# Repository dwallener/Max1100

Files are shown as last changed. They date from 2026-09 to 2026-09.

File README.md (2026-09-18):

# Max 1100 cooling prototype

Current development: four GPUs at a hard **200 W per card**, horizontal motherboard, approximately 3 mm housing gaps. Build and test the suction duct before designing the enclosure.

- [Agreed plan](PROTOTYPE-PLAN.md)
- [Fabrication notes and physical test sequence](FABRICATION-200W.md)
- [200 W prototype CAD source](prototype-200w.scad)
- [Individual STL and gasket DXF parts](prototype-200w/parts/)
- [Exploded assembly](prototype-200w/assembly.png)
- [Blower support layout](prototype-200w/support-layout.svg)
- [200 W versus preserved 300 W design](COMPARISON.md)

## Print first: the fit coupon

Print [fit-coupon.stl](prototype-200w/parts/fit-coupon.stl) on its broad face: approximately 78 × 117 mm on the bed and 6 mm tall. PLA is suitable for this unpowered fit check. Try it over two adjacent GPU housing ends without forcing it or pressing against circuit boards or fins. This checks the approximate housing profile and 3 mm gap before committing to larger prints.

After the coupon fits, trial the complete four-card adapter and connected cable/bracket clearance. The remaining duct parts are approximate development geometry, not thermally validated hardware. No native Onshape document has been created; source CAD is OpenSCAD.

## Rebuilding the exports

Install OpenSCAD and make its `openscad` command available on your PATH, then run from the repository root:

```sh
sh prototype-200w/export.sh
```

The script regenerates the individual STL parts, gasket DXFs and exploded assembly PNG. CAD sources, fabrication exports, previews and manufacturer reference files are tracked so the project can be reviewed and the fit coupon printed without installing CAD software. Export logs, local editor files and duplicate build-package ZIPs are ignored. `part-sizes.json` records the current exported mesh bounds; the export script does not regenerate that report.

The earlier `duct-v1.*`, `DESIGN.md` and `BLOWER-SELECTION.md` describe the preserved 300 W alternative. `duct-200w.*` retain the earlier complete 200 W concept including the blower envelope. `prototype-200w.scad` adds fabrication details without overwriting either concept.

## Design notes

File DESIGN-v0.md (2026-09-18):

# Max 1100 duct prototype, revision 0

Status: packaging concept; not a fabrication release or thermally validated design. No Onshape document has been created. Editable geometry is in duct-v0.scad. All dimensions are millimetres.

## Architecture

Four cards in parallel, each drawing room air through its own heatsink. A sealed card-end adapter feeds a shared suction chamber, a gradual rectangular-to-round transition, and a short 200 mm duct to a separate housed, speed-controlled centrifugal blower. Exhaust stays away from GPU intakes. No 40 mm fans. Motherboard remains horizontal, cards vertical in slots as photographed. CPU cooling is separate and is outside this prototype.

The collector is independently supported. Soft seals contact the card housings, never bare boards or heatsink fins. Bridge, PCIe slots and power connectors carry no duct load. The photographed connector/extension-bracket end is a provisional collector location, NOT a confirmed Intel airflow direction. Verify direction from integration guidance or controlled comparison before fitting the end adapter.

## Airflow basis

Intel datasheet revision 1.0, page 32 gives card pressure drop:

    pressure_inH2O = -0.0137 + 0.0127*q + 0.0007*q^2 - 0.0000002*q^3
    q = per-card flow in CFM; 1 inH2O = 249.09 Pa

At 30 CFM/card: 0.9919 inH2O = 247 Pa; total four-card flow is 120 CFM.
At 40 CFM/card: 1.6015 inH2O = 399 Pa; total four-card flow is 160 CFM.
Parallel cards add flow, not pressure. Assumes comparable paths and good seals.

Initial blower procurement envelope: a manufacturer-confirmed operating point of at least 160 CFM (272 m3/h) at 500 Pa external static pressure, with speed control. This provides a provisional ~100 Pa allowance above the 40 CFM/card curve point for the duct, seals and guards. It is NOT measured system resistance, a guaranteed thermal requirement, or permission to substitute a 160 CFM free-air rating and a separate 500 Pa shutoff rating. Check hot-air rating and the actual housed blower curve. No particular blower is selected yet.

At 120 / 160 CFM total, 1,200 W gives ideal bulk air rises of approximately 17.6 / 13.2 C, using air density 1.2 kg/m3 and cp 1005 J/kg K. These do not predict GPU/HBM temperatures. Intel page 29 separately specifies approach velocity versus inlet temperature; establish the relevant inlet measurement area and check that requirement during testing. Do not convert using an assumed open-fin area.

Intel source: https://cdrdv2-public.intel.com/817799/817799_Intel%20Data%20Center%20GPU%20Max%201100%20Datasheet_Rev_1_0.pdf

## Geometry and fabrication status

- Card reference envelopes: 266.7 long, 111.15 high, 34.35 wide (Intel table); assumed 40.64 pitch. Actual seal profile is smaller/different from the full card envelope and must be measured.
- Collector clear section: 180 x 130, length 120. Deliberate service room for cable routing and projecting brackets; check actual harness bend requirements.
- Transition: 220 long, from collector section to 200 clear-diameter outlet. Outlet collar: 40 long. Wall: 3. Joining flanges: 5 thick, 14 wide, M4 clearance holes.
- Approximate duct body length: 380, excluding blower/connecting hose. Envelope including front flanges: 214 wide by 220 high. These are adjustable design choices.
- SCAD includes collector, transition, outlet and reference card boxes. It does NOT include the fitted card-end seal plate, between-card bypass seals, cable pass-throughs, service lid, brackets, pressure taps, guards, print splits or blower mounting. These must be detailed before fabrication.
- Use a sheet-metal collector with removable gasketed lid for first thermal testing; printed transition/collar are options after material temperature limits are checked. Do not assume a printed polymer is suitable from room-temperature fit alone.
- Transition and collar meet at a butt seam in the concept. Add a bonded sleeve or bolted joint before separate fabrication. The 220 mm transition may need splitting for the available printer.

## Test that decides whether to build the enclosure

1. Fit seals and supports with power off. Install a proper CPU/cooler and support the motherboard on standoffs for powered tests. Route and secure GPU power cables, maintaining manufacturer bend clearance. Install blower guard and proper power/control hardware.
2. Run blower first, check bypass leakage and inlet/exhaust separation. Use pressure taps in calm regions upstream and downstream of the card bank with a differential manometer. Keep taps clear of jets. A bank pressure reading cannot prove equal flow through each card.
3. At conservative GPU power, record room/card inlet temperatures, GPU/HBM temperatures, each card's power, clocks and thermal-throttle flags, blower speed, differential pressure and sound at a fixed distance. Log every card, not just an average.
4. Increase load/power in steps, then operate all four at the intended 300 W/card and representative workload. Observe until temperatures settle, then sustain at least 30 minutes. Stop escalation on throttle, uncontrolled temperature rise or any component limit. Test inlet temperature expected in actual use.
5. Pass only with no thermal throttling, sustained intended performance, temperatures below published limits with useful margin, and acceptable measured noise. Use 90 C GPU/HBM as an initial conservative project target, not an Intel specification; verify valid HBM sensor channels and all component-specific limits. Intel notes a disabled HBM stack can report invalid values.
6. Reduce blower speed to find the quietest passing operating point. If one card is hotter, inspect its inlet, seals and obstruction before adding speed. Repeat at maximum expected room temperature and after adding the enclosure/filter/guards because those change resistance.
7. Before unattended operation, tie loss of blower/airflow to workload stop or shutdown. Never rely on a static CAD model to establish thermal safety.

Next physical inputs: actual four-card end profile/pitch, bracket and connected-cable envelope, and intended airflow direction. These are fit-release requirements, not prerequisites to discussing this concept.

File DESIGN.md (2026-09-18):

# Max 1100 cooling prototype, revision 1

Selected blower: Fantech FG 12XL EC #49905, 120 V / 60 Hz. See [selection, evidence and bill of materials](BLOWER-SELECTION.md).

Current editable assembly: duct-v1.scad. duct-v1.stl contains only the custom duct. duct-v1.png shows the assembly. Revision 0 is retained separately for history.

## Current design

Four parallel GPU airflow paths feed a 180 x 130 mm clear collector, 120 mm long. A 550 mm transition leads to a 305 mm nominal connection and straight inlet spool. The purchased blower and its isolation connections sit on an independent frame. CPU and motherboard cooling remain separate. The full straight test layout is approximately 1,695 x 460 x 505 mm, including reference card envelopes.

Intel's pressure polynomial gives approximately 247 Pa at 30 CFM/card and 399 Pa at 40 CFM/card. Four parallel cards therefore need 120 or 160 CFM total at those pressures, plus duct losses. The initial allowance is 160 CFM at 500 Pa at reference density. Fantech's live calculator reaches that point at nearly full drive; hot-air reserve is limited. See the selection note for exact calculator results and limitations.

Status: model checked as manifold and rendered for visual inspection. It has not been fabricated, fit checked, structurally certified or thermally tested. The fan is a purchased-component clearance envelope, not a manufacturer CAD solid. There is no Onshape document yet.

Still required before fabrication: fitted card seals, cable exit profiles, actual GPU pitch, airflow-direction verification, service lid and print splits, collar attachment, and OEM blower bracket mounting holes. Verify purchased coupling fits and keep all assembly load off the GPUs. The blower can be moved remotely without changing the card collector.

## Test that decides whether to build the enclosure

1. Fit seals and supports with power off. Install a proper CPU/cooler and support the motherboard on standoffs for powered tests. Route and secure GPU power cables, maintaining manufacturer bend clearance. Install blower guard and proper power/control hardware.
2. Run blower first, check bypass leakage and inlet/exhaust separation. Use pressure taps in calm regions upstream and downstream of the card bank with a differential manometer. Keep taps clear of jets. A bank pressure reading cannot prove equal flow through each card.
3. At conservative GPU power, record room/card inlet temperatures, GPU/HBM temperatures, each card's power, clocks and thermal-throttle flags, blower speed, differential pressure and sound at a fixed distance. Log every card, not just an average.
4. Increase load/power in steps, then operate all four at the intended 300 W/card and representative workload. Observe until temperatures settle, then sustain at least 30 minutes. Stop escalation on throttle, uncontrolled temperature rise or any component limit. Test inlet temperature expected in actual use.
5. Pass only with no thermal throttling, sustained intended performance, temperatures below published limits with useful margin, and acceptable measured noise. Use 90 C GPU/HBM as an initial conservative project target, not an Intel specification; verify valid HBM sensor channels and all component-specific limits. Intel notes a disabled HBM stack can report invalid values.
6. Reduce blower speed to find the quietest passing operating point. If one card is hotter, inspect its inlet, seals and obstruction before adding speed. Repeat at maximum expected room temperature and after adding the enclosure/filter/guards because those change resistance.
7. Before unattended operation, tie loss of blower/airflow to workload stop or shutdown. Never rely on a static CAD model to establish thermal safety.

Next physical inputs: actual four-card end profile/pitch, bracket and connected-cable envelope, and intended airflow direction. These are fit-release requirements, not prerequisites to discussing this concept.

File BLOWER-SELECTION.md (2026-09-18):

# Selected blower and integration, revision 1

Selected for the prototype: **Fantech FG 12XL EC, item 49905, 120 V / single phase / 60 Hz**. This is a complete housed centrifugal inline fan. No purchase has been made. Current vendor stock, lead time and price have not been verified.

## Selection evidence

The live Fantech product selector and its embedded Systemair calculation tool were inspected on 2026-09-18. Product 49905, variant 99711, calculator version 2026-09-02.07:32. Source:
https://www.fantech.net/en-us/products/fans-and-accessories/inline-duct-fans/fg?sku=49905

At air density 0.075 lb/ft3, input 160 CFM and 2.01 in.wg (~501 Pa), the calculator returned:

| Quantity | Manufacturer calculator result |
|---|---:|
| Working airflow | 160 CFM |
| Working static pressure | 2.01 in.wg |
| Input power | 125 W |
| Fan speed | 2,635 RPM |
| Control signal | 9.8 V |
| Current | 1.60 A |
| Inlet sound power | 71 dB(A) |
| Outlet sound power | 73 dB(A) |

These are calculated fan operating-point data, not measurements of this GPU assembly. Sound power is NOT sound pressure at the listener and must not be advertised as a 73 dBA room noise level. The operating RPM differs from the nominal product-sheet RPM; it is reported as the calculator result without substituting it for the nameplate rating.

This meets our initial reference-density sizing point with little remaining speed-control margin. A second calculation at entered density 0.0675 lb/ft3 (display rounded to 0.068) returned 155 CFM, 2.09 in.wg and 10.0 V rather than the requested point. Thus it is NOT a verified 160 CFM / 500 Pa selection at hot exhaust density. System resistance also changes with density, but the actual nonuniform heated card/duct system must be measured. Do not assume constant cooling mass flow as air temperature rises. The selection is for the test prototype, not an unconditional thermal guarantee.

An older 2016 brochure lists a 1.96 in.wg shutoff pressure for the same model. The newer 2025 makeup-air table lists 2.51 in.wg. We used the live manufacturer's model-specific calculator instead of mixing those versions. Obtain a current submittal matching the supplied unit before purchasing old stock or a used blower.

The older FG8 EC and FG10 EC tables do not meet 160 CFM at 500 Pa; extra free-air capacity does not compensate for insufficient pressure. The selected 12-inch fan's size is accepted because the user prioritized function over footprint.

## Physical integration in duct-v1.scad

- Replace the earlier 200 mm outlet with **305 mm nominal duct size**. Printed adapter is 305 mm OD / 299 mm ID, 3 mm wall. This is an interface design choice; measure fan spigot OD and chosen clamp fit before printing. No interference fit is assumed.
- Keep the provisional 180 x 130 mm collector clear section and 120 mm service chamber.
- Increase transition length to 550 mm and raise round centerline to 220 mm above the card-envelope datum. This clears the large fan casing while retaining a gradual connection. No CFD validation is claimed.
- Provide a 305 mm long straight sheet-metal inlet spool, with resilient FC12 connection envelopes at each end. Straight length is a design allowance, not a certified manufacturer's minimum. Alter if commissioning shows inlet distortion.
- Model the fan as a **406 mm diameter purchased-component envelope**, with 170 mm axial body, 38 mm and 25 mm necks: 233 mm end-to-end. Dimensions follow the 2025 IOM, printed page 19. The terminal box uses published 95 mm width and 51 mm height; its 70 mm depth is an explicit clearance assumption. Casting shape and internal rotor are intentionally not modeled.
- Physical fan arrow must point away from the GPUs. The reference model does not establish fan inlet/outlet by silhouette. If the 38/25 mm necks fall on opposite sides, swap the two parameters and reposition the spool by 13 mm.
- Add an independent steel frame 460 mm wide and 313 mm long beneath the blower; OEM mounting bracket connects to adjustable side supports. Exact bracket holes and final bracket-to-rail fasteners require the received bracket. The frame is a support layout, not a released drilling drawing or load-certified structure.
- Retain a 150 mm outlet stub and native 12-inch connection for a guard / optional silencer. Do not leave the fan accessible without a suitable guard. Optional LD12 silencer is not included in the current geometry or loss allowance as a validated item.
- Total modeled run including 266.7 mm card envelopes is approximately 1,695 mm long, 460 mm wide at the support, and 505 mm tall from frame bottom to terminal-box top. The blower can be placed remotely; this straight test-bench arrangement is not the final case footprint.

SCAD part selectors: assembly (purchased references included), duct (custom collector + transition + collar only), collector, transition, outlet, stand. The delivered STL contains only the custom duct, not the purchased blower. It is still a fit-prototype mesh, not a print release; segmentation, service lid, card seals, cable glands and transition/collar joint details remain pending. Reference GPU pitch remains assumed.

## Prototype bill of materials

| Qty | Item | Status / purpose |
|---:|---|---|
| 1 | Fantech FG 12XL EC, 49905, 120 V 60 Hz | Selected blower; current supplied version must match curve |
| 1 | Fantech EC-10V, 498148 | Optional accessible manual speed controller; built-in potentiometer can commission first |
| 2 packs | Fantech FC12, 411123 (2 clamps per pack) | Three modeled connection positions, one spare; verify allowable joint gap/OD |
| 1 | 12-inch straight metal duct, 305 mm long | Inlet spool; deburr and seal joints |
| 1 | 12-inch straight metal duct, 150 mm long | Outlet stub |
| 1 | Guard appropriate to accessible outlet | Verify attachment and exhaust suitability; do not substitute an obstructive grille |
| 1 set | Independent metal support + OEM bracket + isolation mounts | Mount pattern to actual supplied bracket; size mounts for fan/frame load |
| 1 set | Collector, transition, seals and pressure taps | Custom parts; fit details pending |
| Optional | Fantech LD12, 411287 | Exhaust attenuation if noise testing requires it; remeasure pressure/flow |

Accessories and item IDs were listed on the selected blower's live manufacturer page. No dimensions of purchased clamps, mounts, guard or silencer are asserted as verified.

## Electrical and commissioning decisions

Use the manufacturer's 120 V mains connection and protective earthing, with enclosed terminals and strain relief. This fan is not powered by a motherboard fan header. Speed control is its built-in potentiometer or compatible 0-10 V controller; do not reduce mains voltage with a household dimmer. Follow the supplied revision-specific wiring diagram rather than assuming PC PWM/tach pin compatibility.

Maximum transported-air temperature is 140 F / 60 C. Measure air entering the blower; start with an alarm target of 50 C to leave margin. The initial 160 CFM / 500 Pa sizing point is almost full drive. Reduce speed only after per-card thermal testing shows sufficient margin. A larger blower can remove the 40 mm tonal whine without being quiet at high pressure: acoustic acceptance remains a physical test.

Continue the staged per-card test in DESIGN.md. At final load, measure card inlet/outlet air, GPU/HBM temperature, delivered flow, pressure drop, electrical power and sound. If hot-air testing needs more pressure or unacceptable speed, revise the blower selection rather than claiming the prototype meets the target.

## Saved manufacturer references

- sources/fantech-fg-installation-2025.pdf: mounting, control, thermal limits and dimensions (printed pp. 1, 7-10, 16-19).
- sources/fantech-fg-ec-submittal-2023.pdf: earlier dimensional comparison; 2025 IOM wins where neck lengths differ.
- sources/fantech-dimensions.png: dimension-letter drawing from live product page.

Direct manufacturer documents:
https://stepimassets.blob.core.windows.net/dsassetsprod/400017_IOM_FG_EN_20250305_211356199.PDF
https://stepimassets.blob.core.windows.net/dsassetsprod/483358_FG_EC_SUBMITTAL_SHEET_EN_20230130_230036535.PDF
https://stepimassets.blob.core.windows.net/dsassetsprod/E1574_MAKEUP_AIR_SYSTEM_20250114_203357183.PDF

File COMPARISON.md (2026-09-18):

# Four Max 1100 GPUs: 200 W versus 300 W per card

Both designs are retained. The previous 300 W files (`duct-v1.*`, `BLOWER-SELECTION.md`, `DESIGN.md`) are unchanged. Their SHA-256 hashes are recorded in `preserved-300w-sha256.json`. The new alternative is `duct-200w.scad`; `compare-power-designs.scad` displays both at the same scale.

## Comparison

| Design quantity | Previous 300 W/card | New 200 W/card |
|---|---:|---:|
| GPU heat, four cards | 1,200 W | 800 W |
| Provisional total airflow | 160 CFM | 120 CFM |
| Provisional system pressure | 500 Pa | 300 Pa |
| Per-card airflow | 40 CFM | 30 CFM |
| Intel card pressure at that flow | 399 Pa | 247 Pa |
| Allowance for other losses | ~101 Pa | ~53 Pa |
| Blower | FG 12XL EC #49905 | FG 8 EC #49901 |
| Nominal duct connection | 305 mm / 12 inch | 203 mm / 8 inch |
| Blower casing diameter | 406 mm | 337 mm |
| Collector length | 120 mm | 120 mm |
| Transition length | 550 mm | 300 mm |
| Straight inlet spool | 305 mm | 203 mm |
| Custom duct length, including collar | 710 mm | 460 mm |
| Whole straight test layout including cards | 1,695 mm | 1,262 mm |
| Maximum width, at support frame | 460 mm | 380 mm |
| Height, frame bottom to terminal box top | 504 mm | 435 mm |
| Calculated blower input at reference sizing point | 125 W | 55 W |
| Calculated control signal at reference sizing point | 9.8 V | 8.8 V |

The new layout is about 26% shorter, its support is 17% narrower, and custom duct length is 35% shorter. The lengths include different outlet stubs (150 mm versus 100 mm). These are complete straight test rigs, not motherboard/enclosure dimensions. The blower may later be relocated alongside the enclosure. Retaining the large fan at 200 W is also possible; downsizing is a packaging choice, not a requirement of the power cap.

## New blower verification

Selected: Fantech FG 8 EC #49901, 120 V, single phase, 60 Hz. Manufacturer page and live calculation inspected 2026-09-18:

https://www.fantech.net/en-us/products/fans-and-accessories/inline-duct-fans/fg?sku=49901

Calculator version: 2026-09-02.07:32, FG8 EC, identifiers 29419 / 30018. At 0.075 lb/ft3 density, requested 120 CFM and entered 1.205 in.wg (display rounded to 1.21), returned working values:

- 120 CFM, 1.21 in.wg (approximately 301 Pa)
- 55 W input, 2,386 RPM, 0.86 A, 8.8 V control
- Inlet sound power 66 dB(A), outlet sound power 67 dB(A)

At entered density 0.068 lb/ft3 (approximately 1.089 kg/m3, representing warm air near 50 C at sea-level pressure), with the same requested point, the calculator returned 120 CFM, 1.33 in.wg, 61 W, 2,493 RPM, 0.99 A and 9.3 V control; inlet/outlet sound power 67/69 dB(A). Reported working pressure differs from the request; do not conceal that or treat the result as a measured system operating point. Both calculations remain below the 10 V maximum control signal.

These are manufacturer calculations, not hardware tests. Sound power is not sound pressure at the desk; the 6 dB difference from the older design's reference outlet sound-power result does not establish a 6 dB room-noise reduction. Both may still need attenuation.

The live product data gives 80 W nominal input, 1.28 A nominal current, 337 mm casing diameter, 152 mm body depth with two 25 mm spigots, 8.4 lb weight and a maximum transported-air temperature of 140 F / 60 C. The body plus spigots occupies 202 mm axially. Terminal-box width/height are 95/51 mm; the model's 70 mm box depth is an explicit packaging allowance. Exact casing shape and mounting pattern are not reproduced.

## Why 120 CFM

At equal bulk temperature rise, two-thirds of the previous 160 CFM would be approximately 107 CFM. The new 120 CFM target gives some extra airflow. At 800 W and 120 CFM, the ideal bulk temperature rise is approximately 11.7 C at air density 1.2 kg/m3 and cp 1005 J/kg K. GPU/HBM junction temperatures cannot be inferred from this calculation.

Intel pressure polynomial: `249.09 * (-0.0137 + 0.0127*q + 0.0007*q*q - 0.0000002*q*q*q)` Pa, q in CFM per card. At 30 CFM per card it gives 247 Pa. Four parallel paths add flow, not pressure. The 300 Pa total target leaves only about 53 Pa at reference conditions for transition, fittings, guards and leakage effects. A filter or silencer must be evaluated separately; no unverified loss allowance is assigned to one.

Intel source: https://cdrdv2-public.intel.com/817799/817799_Intel%20Data%20Center%20GPU%20Max%201100%20Datasheet_Rev_1_0.pdf

## New geometry and parts

- Same provisional 180 x 130 mm collector and card interface as the previous version. 200 W concept now uses the user-provided approximate 3 mm housing gap: 37.35 mm pitch and 146.4 mm bank width. The preserved 300 W model retains its original 40.64 mm pitch; both remain nominal packaging assumptions, not claims about actual PCIe slot centers.
- 300 mm transition, outlet centerline 185 mm above card reference datum.
- 203 mm OD / 197 mm ID custom collar; confirm compatibility with actual purchased clamp and fan spigot OD. Nominal 8-inch connections are not asserted to be exact machined diameters.
- Straight metal inlet: 203 mm; outlet stub: 100 mm. These are design allowances, not claimed manufacturer minimum lengths.
- Independent 380 x 282 mm steel support-frame envelope. Bracket placement and holes must fit the supplied OEM mounting bracket. No load is carried by the card bank. Frame is not structurally certified.
- Three generic resilient joint envelopes sized for an 8-inch connection, replacing the 12-inch joints. Use compatible FC8-type isolation clamps; verify dimensions/gap capacity before purchase or fabrication.
- Speed control: built-in potentiometer initially, optional compatible EC-10V controller. Follow manufacturer wiring, separate 120 V supply and protective earthing; no motherboard-header power.
- Add suitable outlet guard; optional 8-inch silencer only after pressure and noise testing.

The STL contains custom duct only. Purchased fan, spool, clamps and support envelope are shown in the assembly render. Neither variant is print-ready: service lid, printable splits/joints, fitted card seals, cable exits, GPU airflow direction and actual bracket mounting details remain unresolved. No component was bought and no Onshape document was created.

## Test and power-cap requirement

The 200 W limit means TOTAL board power per GPU, enforced before workload launch and restored after reboot, driver reset and recovery. If the limit cannot be verified, do not start the workload. Brief power transients and fan failure still require thermal monitoring and workload shutdown.

Use the existing staged procedure in DESIGN.md, substituting 200 W/card for the final load. Test all four cards concurrently at the highest expected inlet temperature. Record actual power cap and draw, GPU/HBM temperatures, sustained clocks, thermal-throttle flags, inlet/exhaust temperatures, airflow, differential pressure and sound at a fixed listener distance. Demonstrate stable temperatures and sustained operation before accepting the design. Stop load on airflow loss or invalid cap state. No performance-loss percentage from the cap is assumed; benchmark the intended workload.

## Approximate card-end interface update

The 200 W concept now includes a replaceable four-window adapter, short housing sleeve with between-card webs, and an overlapping removable roof panel. An exploded interface preview is in interface-200w.png. No additional measurement is needed to continue conceptual work.

The adapter uses four 34.35 x 111.15 mm reference card envelopes, separated by the user's approximate 3 mm gap. Provisional per-side clearance is 0.4 mm, leaving 2.2 mm rigid webs between windows. Overall bank width is 146.4 mm. The 8 mm adapter plate bolts to the existing collector flange; a 15 mm sleeve overlaps the housing ends. These windows represent full packaging envelopes, not measured heatsink apertures. Soft gasket lips, electrical clearances and contact surfaces remain to be refined. The collar must not clamp bare boards or fins.

The 120 mm chamber reserves room for the photographed end brackets and power harness. Four provisional 18 mm roof holes mark split-grommet cable routes; hole sizes and locations are placeholders, not connector pass-through dimensions. Split glands permit installation around connected cables. The lid is shown raised only in the exploded view; in the assembly it overlaps the roof opening. Lid fasteners, gasket details and individual gland inserts are not yet modeled. Actual harness routing can change without replacing the long transition.

Part selectors adapter and lid export these separately; interface shows the close-up. adapter-200w.stl is a validated concept mesh, not a fabrication release. The main duct STL excludes the separate adapter and lid. Power-cap, airflow-direction and physical validation assumptions above still apply. Prior 300 W files are preserved unchanged.

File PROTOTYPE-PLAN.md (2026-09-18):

# Max 1100 cooling prototype: agreed plan

2026-09-18. Proceed on four GPUs, each with a hard 200 W total-board-power limit. Motherboard horizontal; GPU housings approximately 3 mm apart. Precise measurements are not a prerequisite for concept development. Retain the 300 W alternative for comparison.

## Decisions

- Sealed suction collector serves four parallel GPU heatsinks. Keep the CPU/motherboard air path separate.
- Use the FG8 EC blower selected in COMPARISON.md. Target 120 CFM at approximately 300 Pa for initial sizing, not a validated cooling guarantee.
- Prototype adapter and seals first; modular duct and independent support second. Enclosure follows successful thermal/noise tests.
- Fit-sensitive dimensions are editable assumptions. Do not make the user remeasure dimensions already documented by Intel.
- No purchases, print jobs or hardware tests have been performed by the assistant.

## This design iteration

Create a fabrication-development source in prototype-200w.scad without changing earlier models. Include a bolt-on adapter, replaceable soft seal strips, split lid and cable grommets, three bolted transition sections, pressure-tap provision, and a support layout. Export individual concept parts and gasket profiles. Check manifold geometry and visually inspect the assembly. Document parts, assembly order and test records.

## Physical progression

1. Print the small two-card fit coupon; check housing clearance and the assumed 3 mm gap with power off. Keep it away from boards and fins. Adjust fit_clearance/card_gap if needed.
2. Fit the complete adapter and soft seals; verify bracket and connected harness clearance in the collector. Confirm GPU airflow direction before powered testing.
3. Fabricate collector/duct sections and support; bolt gasketed joints, fit split cable glands, cap unused pressure taps, mount blower independently and install guards.
4. Verify the 200 W cap on every card before launching load. Start blower first. Increase load in steps, recording per-card temperature, actual power, clock and throttle flags plus inlet/outlet air, airflow, differential pressure and sound.
5. Test all four concurrently at the intended inlet temperature. Once temperatures settle, sustain at least 30 minutes; accept only with no thermal throttling, temperature margin and acceptable noise. Add the enclosure only after passing, then repeat the test.

Physical fit, fabrication, airflow-direction confirmation and live tests require access to the user's hardware. CAD validation does not complete these steps. See FABRICATION-200W.md for the next build package and explicit limitations.

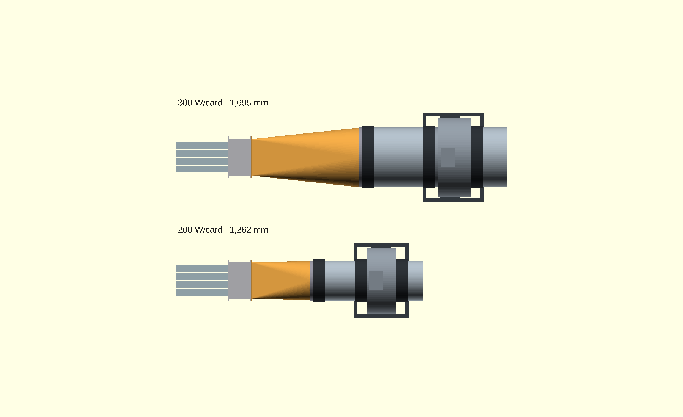
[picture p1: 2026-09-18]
compare-power-designs.png

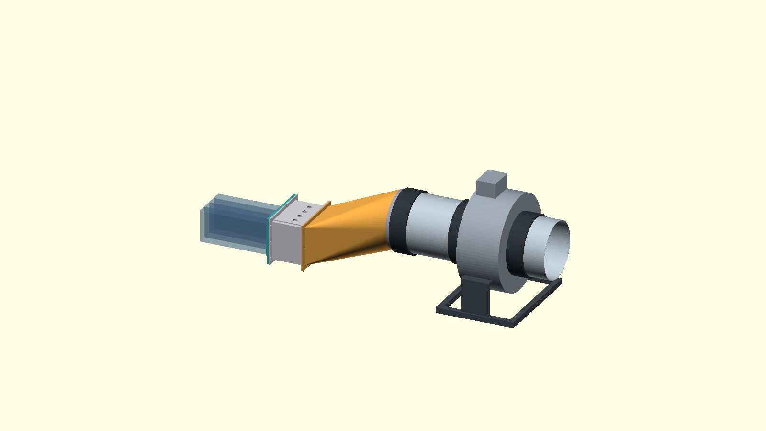
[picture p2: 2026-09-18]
duct-200w.png

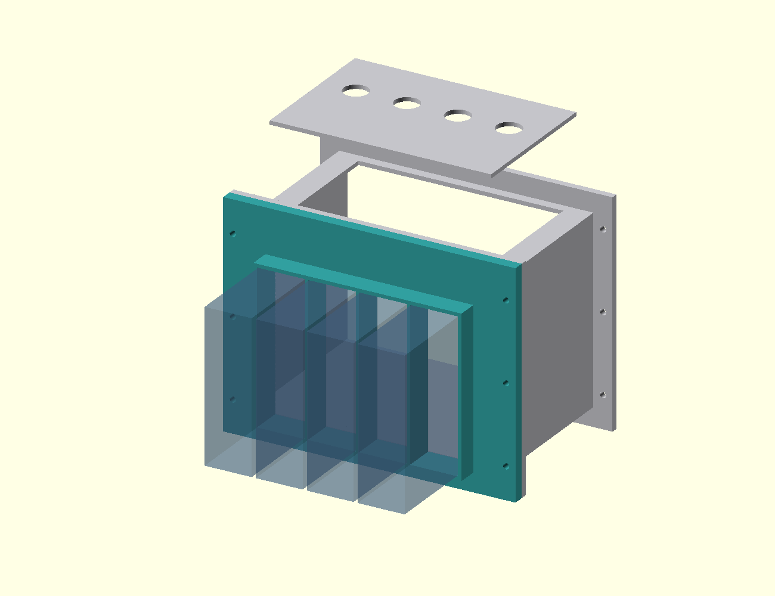
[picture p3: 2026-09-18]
interface-200w.png

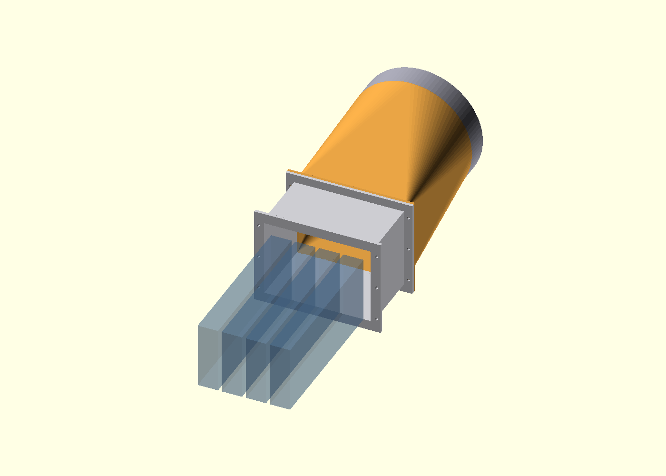
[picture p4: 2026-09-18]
duct-v0.png

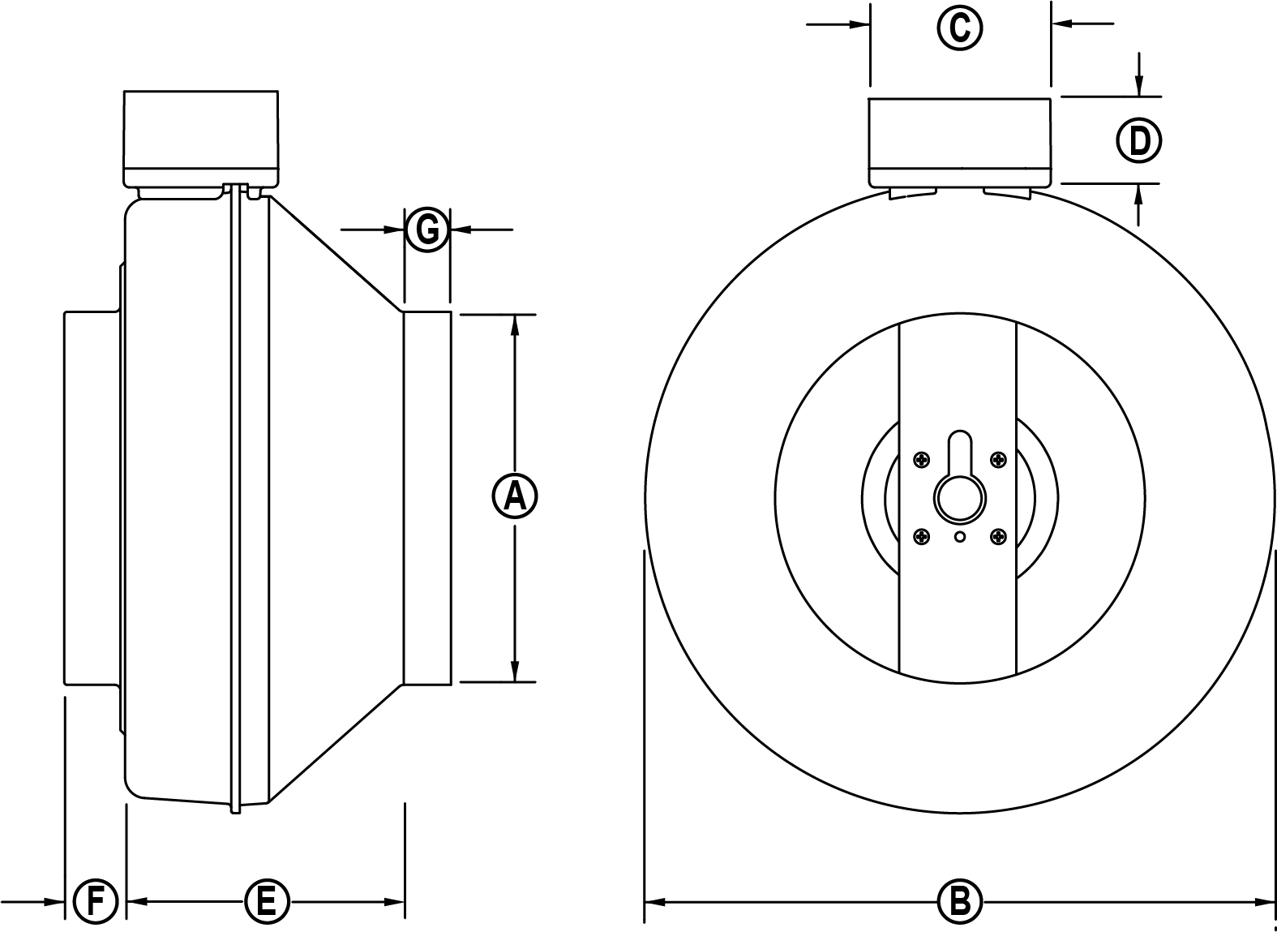
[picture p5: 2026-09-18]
sources/fantech-dimensions.png

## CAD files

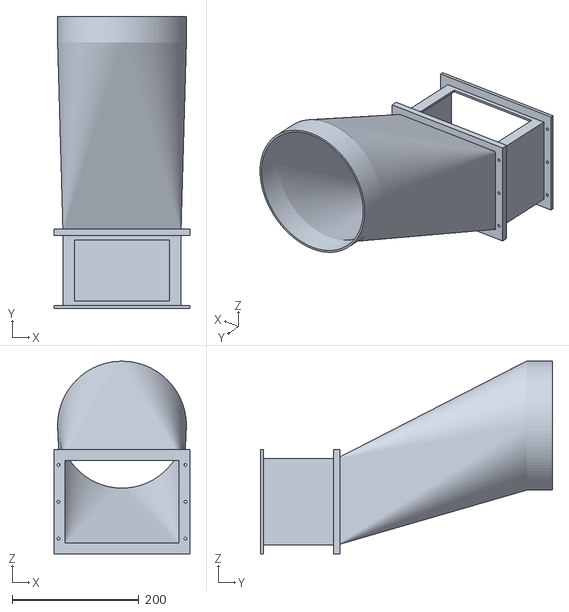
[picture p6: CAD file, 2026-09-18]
duct-200w.stl
214.0 x 460.0 x 303.5

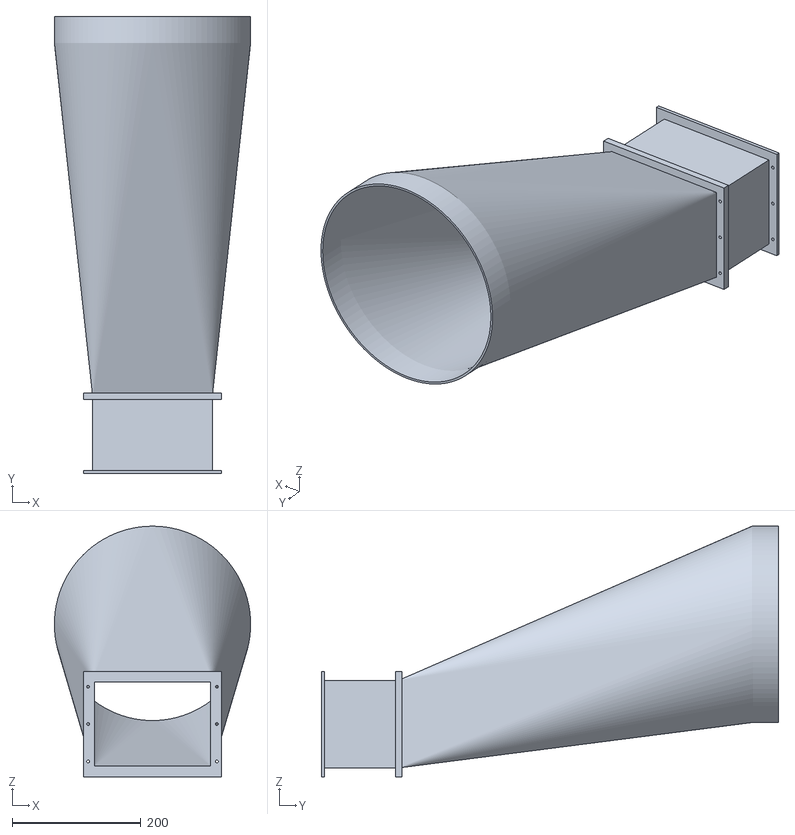
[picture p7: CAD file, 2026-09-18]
duct-v1.stl
305.0 x 710.0 x 389.5

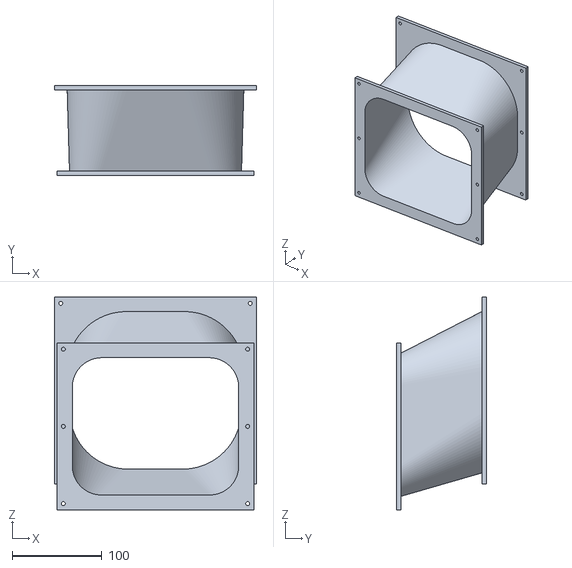
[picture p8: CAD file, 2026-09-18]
prototype-200w/parts/transition-1.stl
225.3 x 100.0 x 237.5

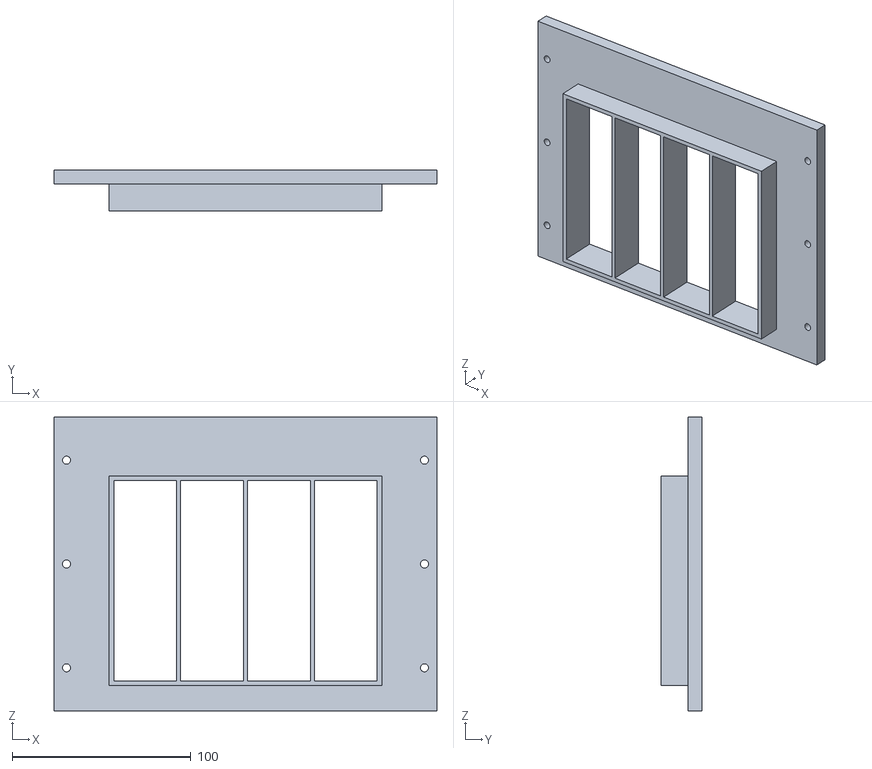
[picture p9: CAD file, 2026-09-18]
adapter-200w.stl
214.0 x 23.0 x 164.0

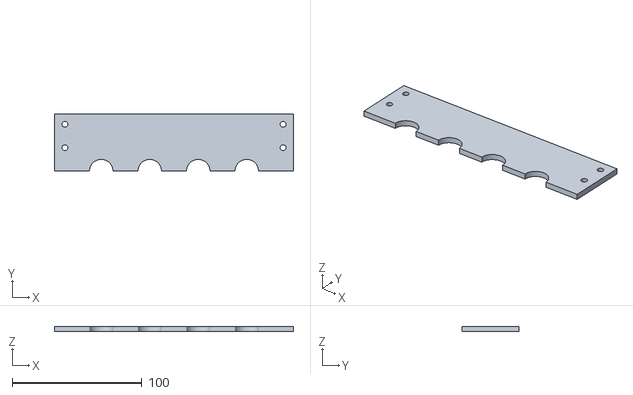
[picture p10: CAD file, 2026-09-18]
prototype-200w/parts/lid-back.stl
184.0 x 44.0 x 4.00

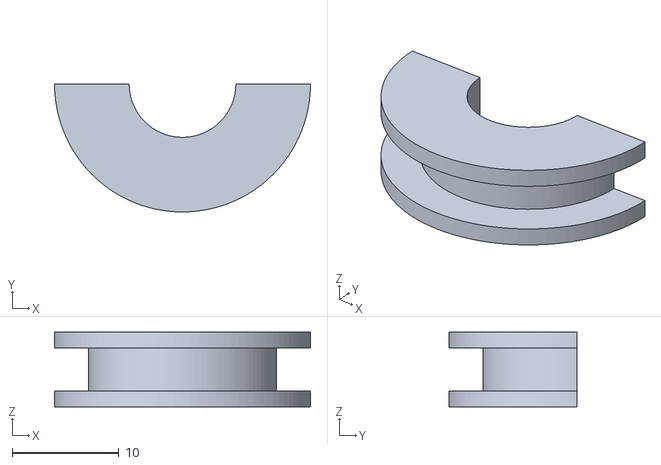
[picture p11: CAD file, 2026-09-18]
prototype-200w/parts/grommet-front.stl
24.0 x 12.0 x 7.00

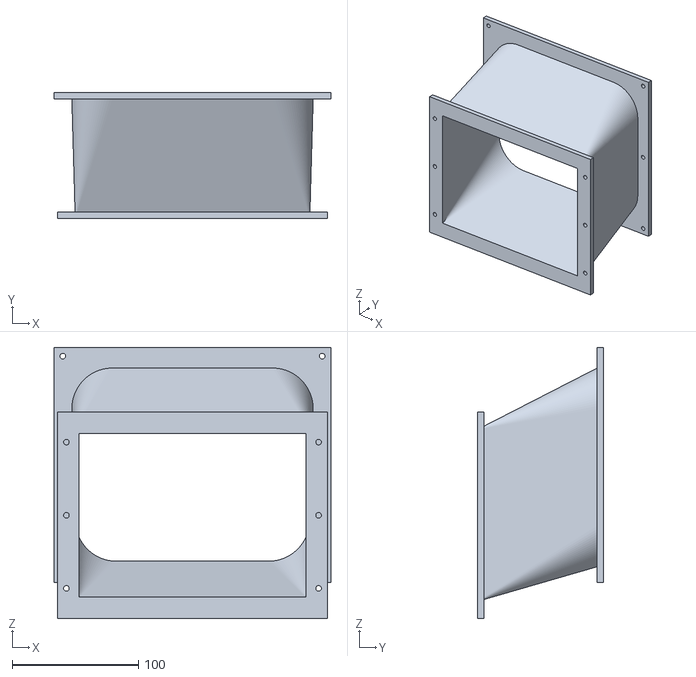
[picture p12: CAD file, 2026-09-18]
prototype-200w/parts/transition-0.stl
219.7 x 100.0 x 215.2

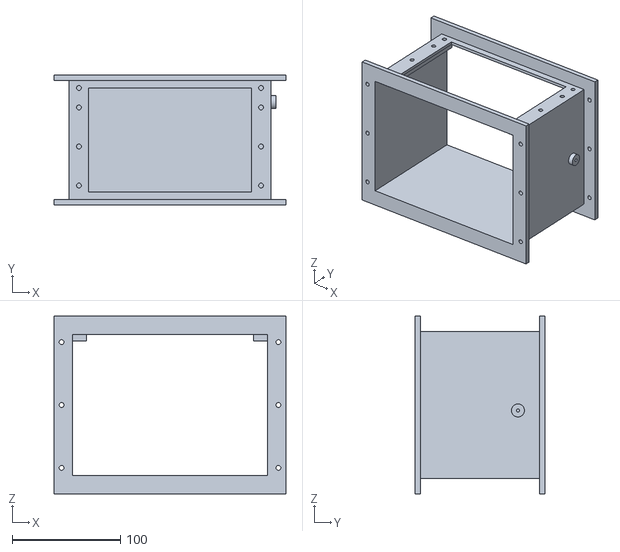
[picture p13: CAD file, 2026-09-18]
prototype-200w/parts/collector.stl
214.0 x 120.0 x 164.0

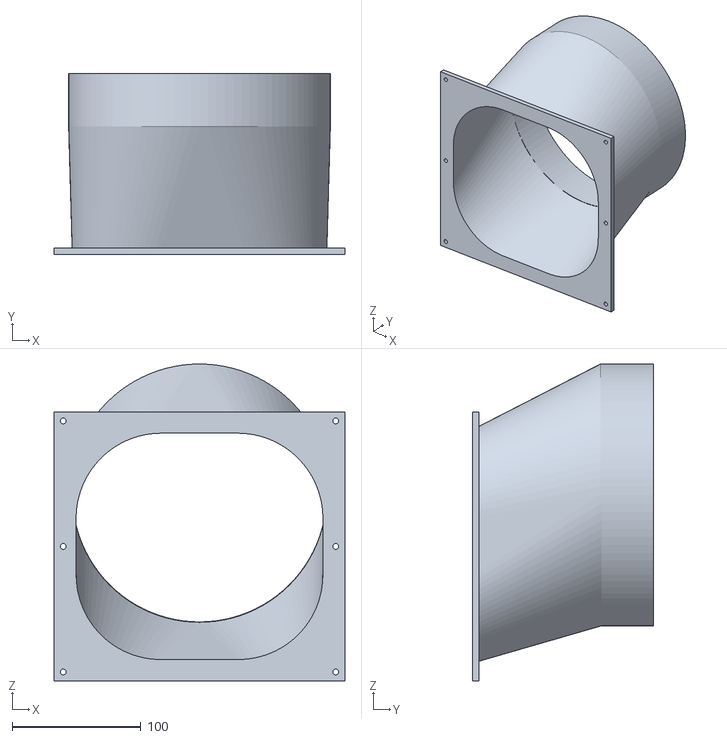
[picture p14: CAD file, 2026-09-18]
prototype-200w/parts/transition-2.stl
225.3 x 140.0 x 245.8

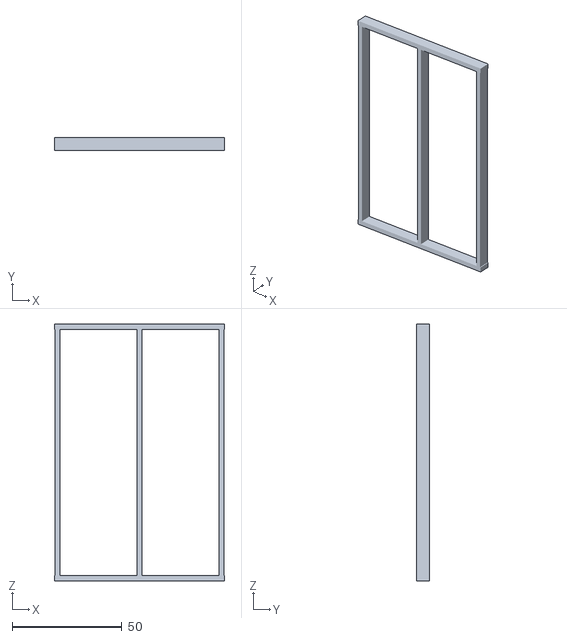
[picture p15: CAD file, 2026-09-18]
prototype-200w/parts/fit-coupon.stl
77.7 x 6.00 x 117.2

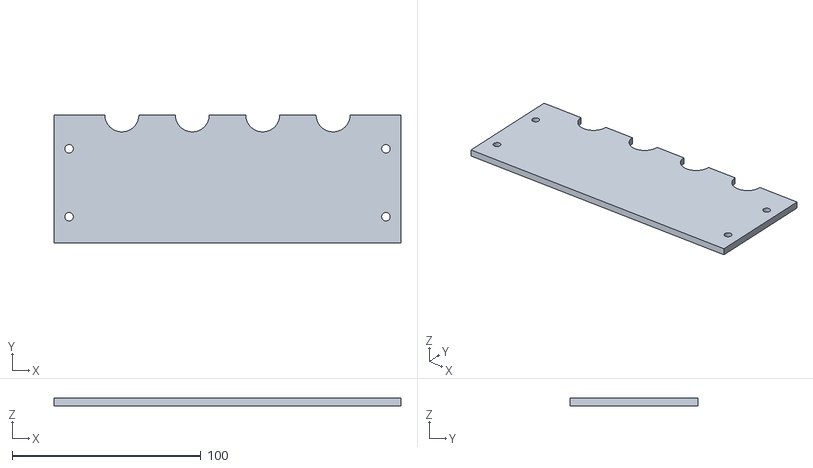
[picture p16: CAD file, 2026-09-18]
prototype-200w/parts/lid-front.stl
184.0 x 68.0 x 4.00

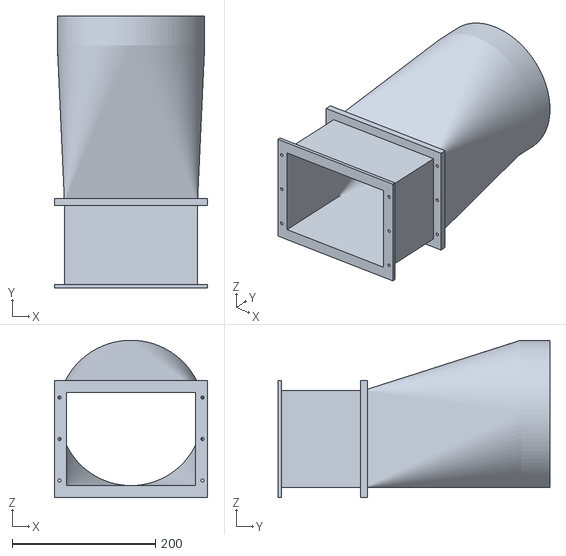
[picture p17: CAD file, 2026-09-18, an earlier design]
duct-v0.stl
214.0 x 380.0 x 220.0

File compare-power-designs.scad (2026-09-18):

// Both alternatives at the same physical scale. Purchased parts are envelopes.
module design300() { include <duct-v1.scad> }
module design200() { include <duct-200w.scad> }
translate([0,0,0]) design300();
translate([630,0,0]) design200();
// Labels are placed in the XY plane for the orthographic top-view render.
color([0.15,0.15,0.15]) {
    translate([-265,-255,0]) rotate([0,0,90])
        linear_extrude(1) text("300 W/card | 1,695 mm",size=32);
    translate([385,-255,0]) rotate([0,0,90])
        linear_extrude(1) text("200 W/card | 1,262 mm",size=32);
}

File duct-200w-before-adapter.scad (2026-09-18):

// MAX 1100 200 W/card + Fantech FG 8 EC #49901. Units mm.
// Requires enforced 200 W total board-power cap before every workload.
// NOT FIT-CHECKED. Card-end seals, cable glands and supports require measurements.
// Air travels along +Y; motherboard is horizontal in XY.
part = "assembly"; // assembly, duct, collector, transition, outlet, stand
show_cards = true;
wall = 3;
mouth_w = 180;       // provisional clear collector width
mouth_h = 130;       // provisional clear collector height
collector_l = 120;   // bracket/cable service volume, verify with actual harness
transition_l = 300;
outlet_id = 197; // 203 mm nominal duct OD less two 3 mm walls
outlet_l = 40;
axis_z = 185; // leaves 16.5 mm below 337 mm blower casing
spool_l = 203; // one nominal diameter straight inlet; design allowance
joint_gap = 10; // FC8 isolating clamp spans butt joint; verify actual clamp
fan_d = 337;
fan_body_l = 152;
fan_inlet_l = 25;
fan_exit_l = 25;
fan_l = fan_body_l+fan_inlet_l+fan_exit_l;
fan_y = collector_l+transition_l+outlet_l+spool_l+2*joint_gap;
exhaust_l = 100;
flange = 14;
flange_t = 5;
bolt_d = 4.5;
card_pitch = 40.64;  // ASSUMED dual-slot pitch, measure installed bank
card_w = 34.35;
card_h = 111.15;
card_l = 266.7;
$fn = 96;

module rect_section(w,h,y,t) {
    translate([-w/2,y,-wall]) cube([w,t,h]);
}
module axial_cylinder(d,y,l) {
    translate([0,y,axis_z]) rotate([-90,0,0]) cylinder(d=d,h=l);
}
module bolt_pattern(y,len) {
    for (x=[-mouth_w/2-wall-flange/2,mouth_w/2+wall+flange/2])
        for(z=[flange/2,mouth_h/2,mouth_h-flange/2])
            translate([x,y,z]) rotate([-90,0,0]) cylinder(d=bolt_d,h=len);
}
module rectangular_flange(y) {
    difference() {
        translate([-mouth_w/2-wall-flange,y,-wall-flange])
            cube([mouth_w+2*(wall+flange),flange_t,mouth_h+2*(wall+flange)]);
        translate([-mouth_w/2,y-1,0]) cube([mouth_w,flange_t+2,mouth_h]);
        bolt_pattern(y-1,flange_t+2);
    }
}
module collector() {
    difference() {
        translate([-mouth_w/2-wall,0,-wall])
            cube([mouth_w+2*wall,collector_l,mouth_h+2*wall]);
        translate([-mouth_w/2,-1,0]) cube([mouth_w,collector_l+2,mouth_h]);
    }
    rectangular_flange(0);
    rectangular_flange(collector_l-flange_t);
}
module transition() {
    difference() {
        hull() {
            rect_section(mouth_w+2*wall,mouth_h+2*wall,collector_l,1);
            axial_cylinder(outlet_id+2*wall,collector_l+transition_l-1,1);
        }
        hull() {
            translate([-mouth_w/2,collector_l-1,0]) cube([mouth_w,2,mouth_h]);
            axial_cylinder(outlet_id,collector_l+transition_l-1,2);
        }
    }
    rectangular_flange(collector_l);
}
module outlet() {
    difference() {
        axial_cylinder(outlet_id+2*wall,collector_l+transition_l,outlet_l);
        axial_cylinder(outlet_id,collector_l+transition_l-1,outlet_l+2);
    }
}
module reference_cards() {
    // Transparent packaging envelopes only; connectors/bridge/brackets omitted.
    for(i=[0:3])
        color([0.3,0.45,0.6,0.35])
            translate([(i-1.5)*card_pitch-card_w/2,-card_l,0])
                cube([card_w,card_l,card_h]);
}
module tube(od,id,y,l) {
    difference() {
        axial_cylinder(od,y,l);
        axial_cylinder(id,y-0.1,l+0.2);
    }
}
module blower_reference() {
    // PURCHASED reference envelope, not a replica or a printable blower.
    // Orient physical airflow arrow away from cards. Spigot ODs nominal;
    // determine actual diameters and bracket hole pattern on received unit.
    color([0.58,0.62,0.66]) {
        tube(203,200,fan_y,fan_inlet_l);
        tube(fan_d,200,fan_y+fan_inlet_l,fan_body_l);
        tube(203,200,fan_y+fan_inlet_l+fan_body_l,fan_exit_l);
        translate([-47.5,fan_y+fan_inlet_l+15,axis_z+fan_d/2-1])
            cube([95,70,52]); // box depth 70 provisional; 95 x 51 sourced
    }
}
module clamp_reference(y) {
    // Generic isolation clamp envelope, FC8 exact size not asserted.
    color([0.18,0.20,0.22]) tube(217,203,y-25,60);
}
module stand() {
    // Independent steel support frame. Drill OEM bracket holes on receipt.
    // No load carried by GPUs, bridge, or duct joints.
    for(x=[-190,170]) translate([x,fan_y-40,-30]) cube([20,fan_l+80,20]);
    for(y=[fan_y-40,fan_y+fan_l+20])
        translate([-190,y,-30]) cube([380,20,20]);
    // Side rails to receive the OEM bracket; final bracket location adjustable.
    for(x=[-185,175]) {
        translate([x,fan_y+50,-10]) cube([10,100,120]);
        translate([x<0?-185:155,fan_y+50,100]) cube([30,100,10]);
    }
}
module duct() {collector(); transition(); outlet();}
if(part=="collector") collector();
if(part=="transition") translate([0,-collector_l,0]) transition();
if(part=="outlet") translate([0,-collector_l-transition_l,0]) outlet();
if(part=="duct") duct();
if(part=="stand") stand();
if(part=="assembly") {
    color([0.8,0.8,0.82]) collector();
    color([0.85,0.6,0.25]) transition();
    color([0.6,0.6,0.65]) outlet();
    color([0.7,0.75,0.79])
        tube(203,201,collector_l+transition_l+outlet_l+joint_gap,spool_l);
    clamp_reference(collector_l+transition_l+outlet_l);
    clamp_reference(fan_y-joint_gap);
    blower_reference();
    color([0.7,0.75,0.79]) tube(203,201,fan_y+fan_l+joint_gap,exhaust_l);
    clamp_reference(fan_y+fan_l);
    color([0.25,0.28,0.31]) stand();
    if(show_cards) %reference_cards();
}

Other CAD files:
prototype-200w/parts/joint-gasket-0.dxf
prototype-200w/parts/joint-gasket-1.dxf
prototype-200w/parts/grommet-back.stl
prototype-200w/parts/face-gasket.dxf
prototype-200w/parts/lid-gasket.dxf
duct-200w.scad
duct-v1.scad
duct-v0.scad
prototype-200w.scad

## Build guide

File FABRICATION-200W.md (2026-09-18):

# Four Max 1100 GPUs: 200 W prototype build notes

2026-09-18. Development parts, in millimetres. These exports are suitable for fit trials; hardware fit and thermal performance remain untested. The earlier 300 W design is preserved unchanged.

## Design basis

Four parallel card passages feed a sealed suction collector, a three-piece expanding transition, a nominal 203 mm straight inlet spool and the Fantech FG8 EC #49901. Each GPU must stay at or below 200 W total board power. Initial sizing is 120 CFM total at approximately 300 Pa; see [COMPARISON.md](COMPARISON.md) for manufacturer evidence and operating-point limitations. CPU and motherboard cooling require a separate air path.

The card reference envelope is 266.7 × 111.15 × 34.35 mm, with an assumed 3 mm housing gap. This gives a 37.35 mm pitch and 146.4 mm bank width. These envelopes do not establish the actual seal surface, brackets or connected harness geometry. The 120 mm collector provides provisional service space. Confirm which end should exhaust before testing; suction direction shown in CAD is an assumption.

## Files and quantities

Source: `prototype-200w.scad`. Exports: `prototype-200w/parts/`. Rebuild using `sh prototype-200w/export.sh` with OpenSCAD installed. All STL coordinates are in assembly space: rotate and place each part on the bed in the slicer.

| File | Build quantity | Purpose |
|---|---:|---|
| fit-coupon.stl | 1 first | Short two-card clearance trial; not an operating duct |
| adapter.stl | 1 after coupon | Replaceable four-window housing collar |
| collector.stl | 1 | Common chamber, lid rails and pressure-tap boss |
| lid-front.stl, lid-back.stl | 1 each | Split roof closes around connected cables |
| grommet-front.stl, grommet-back.stl | 4 each | Split flexible cable seals; provisional 10 mm bores |
| transition-0/1/2.stl | 1 each | Successive bolted duct sections |
| lid-gasket.dxf | 1 | Lid perimeter gasket |
| face-gasket.dxf | 2 | Adapter/collector and collector/transition seals |
| joint-gasket-0/1.dxf | 1 each | Two transition seam seals |

DXFs are full-size millimetre profiles, with bolt holes. Check one known dimension before cutting: face gasket width 214 mm. Gasket material and bolt washers/spacers are additional purchased/cut parts, not STL meshes. The blower, straight spool, isolation couplings, outlet guard and support are not included among these ten STL files.

## Fit and print sequence

1. Print the coupon flat on its broad face (approximately 78 × 117 mm footprint, 6 mm tall). With power off, try it against two adjacent housing ends. Never force the coupon onto fins, a PCB or connectors. Its rectangular windows are deliberate approximations; change the profile if the actual seal land differs.
2. Adjust `card_gap` and `fit_clearance` in the source if needed. Current clearance is 0.4 mm per side before adding seals. Print the full adapter and verify all four housings, bracket clearance and how it can be installed. Only proceed once it fits without transferring load to the cards.
3. Mock up the connected harness inside the collector envelope, including connector bend clearance. Four 18 mm roof openings contain split inserts with 10 mm cable bores. Edit `cable_bore` inside `grommet()` to suit the actual bundle; these are seals, not certified strain reliefs. Anchor cables independently on the support.
4. Print collector, lid and transition sections. The three transition sections are approximately 220 × 215, 225 × 238 and 225 × 246 mm across their ends, with lengths 100, 100 and 140 mm. A 300 mm bed accommodates these orientations and a brim; smaller machines may need another split. Collector envelope is 214 × 120 × 164 mm. Full bounds are recorded in `prototype-200w/part-sizes.json`.
5. Orient duct axes vertically where practical and inspect the slicer for flange overhangs and the collector roof rails. Use supports where needed. The model has nominal 3 mm walls; choose enough perimeters to make these solid, inspect seams and check for leakage. No universal slicing recipe is assumed.

Use a rigid material whose published continuous-service rating exceeds the measured local temperature with margin; make that choice before a powered test. A cold fit coupon may use ordinary prototype material. Use suitably rated compliant material for seals; the grommet shapes can also serve as tooling references for silicone parts. Filament type alone does not establish suitability.

## Seals and fasteners

- Line each collar window with replaceable soft strips, approximately 10 mm deep along the card. CAD shows 0.6 mm material compressed into 0.4 mm clearance. Treat this as a starting compression trial, not an established gasket specification. Seal against solid housing only, leaving fins and other intended openings clear.
- Use nominal 2 mm compliant sheet for flange and lid gaskets, initially targeting 1 mm compressed thickness. Confirm the material's recommended compression and use stops/shims to prevent crushing printed parts. The lid has a modelled 1 mm gap; flange gaskets add about 4 mm total axial stack across four joints, which is not included in the nominal CAD placement. Allow the support and spool alignment to move accordingly.
- Eight M4 bolts retain the lid. Six M4 bolts serve each of four duct flange joints: 24 flange bolts. All modelled clearance holes are 4.5 mm. Start with 14 M4 × 25 mm bolts (eight lid, six adapter joint), and 18 M4 × 20 mm bolts (remaining joints), plus washers and nuts. Confirm length and wrench access during dry assembly; substitute lengths as needed. Nuts are loose, not captured inserts.
- The two lid halves butt at the cable openings. Seal the exposed butt seam with removable temperature-rated airtight tape, and close the split grommet seams around the cables. There is no hidden overlapping seal at this joint. The removable perimeter gasket remains one piece.
- Use a small nipple fitted and sealed into the pressure boss; the model has a 3 mm pilot bore and 12 mm outer boss. Drill/fit it to the selected fitting and cap it when unused. Keep the internal opening flush and clear. Measure collector static pressure relative to the intake reference; this alone is not an airflow measurement.
- Support collector and blower independently. No blower weight, duct leverage or cable tension should be carried by the GPU housings. Use compatible isolation couplings at the spool and blower and prevent exhaust recirculation into the card inlets.

## Metal support layout

See `prototype-200w/support-layout.svg`: a provisional 380 × 282 mm rectangular base using 20 mm square tube, with slotted mounting straps for the supplied blower bracket. Cut two 282 mm side rails and two 340 mm cross rails for butt joints. Strap and bracket hole positions must be transferred from the actual supplied bracket. Establish height with the actual bracket so the inlet centre is 185 mm above the CAD reference plane; the 337 mm body then has nominal 16.5 mm bottom clearance. The reference plane is not necessarily the underside of the motherboard tray.

Use a separate adjustable cradle under the collector/transition, with compliant pads and straps outside the airflow path. Its exact height follows the motherboard standoffs and actual card seal land; it is intentionally not fixed by this drawing. Base feet, bracket fasteners and support strength need a shop fit check. This is a layout and cut list, not a released production drawing.

## Bench test and acceptance record

Before load, confirm correct airflow direction, unobstructed inlets, sealed joints and installed guards. Run the blower first. Verify the enforced 200 W board-power cap on every card, including after reboot or driver reset. Increase load in steps; stop escalation if temperatures keep climbing toward a device limit or any card throttles.

Record at every step: ambient/card inlet temperature; each card's actual board power, reported temperatures, clocks and thermal-throttle flags; collector/outlet air temperatures; collector pressure; independently measured flow; blower control setting; sound level at a fixed, documented distance. Repeatable sound measurements allow comparison even if the instrument is not calibrated.

Test all four simultaneously at the intended worst inlet temperature. After temperatures settle, sustain at least 30 minutes. Pass only with no thermal throttling, margin to the applicable device temperature limits, and noise acceptable to the user. Compare individual cards: a cool average must not conceal an undercooled passage. Then build the enclosure and repeat the thermal test with it fitted.

| Date / load step | Inlet °C | GPU power/temperature/throttle, all four | Flow / pressure | Blower setting / sound | Result |
|---|---|---|---|---|---|
| Not yet tested | — | — | — | — | Awaiting hardware fit trial |

## Digital checks completed

Ten STL exports completed with OpenSCAD manifold status `NoError`. Four gasket DXFs exported as nonempty 2D geometry. Exploded assembly visually reviewed and part bounds recorded. These checks establish export integrity, not mechanical fit, print quality or cooling performance. Original 300 W model, render, mesh and selection/design documents retain their recorded SHA-256 hashes.

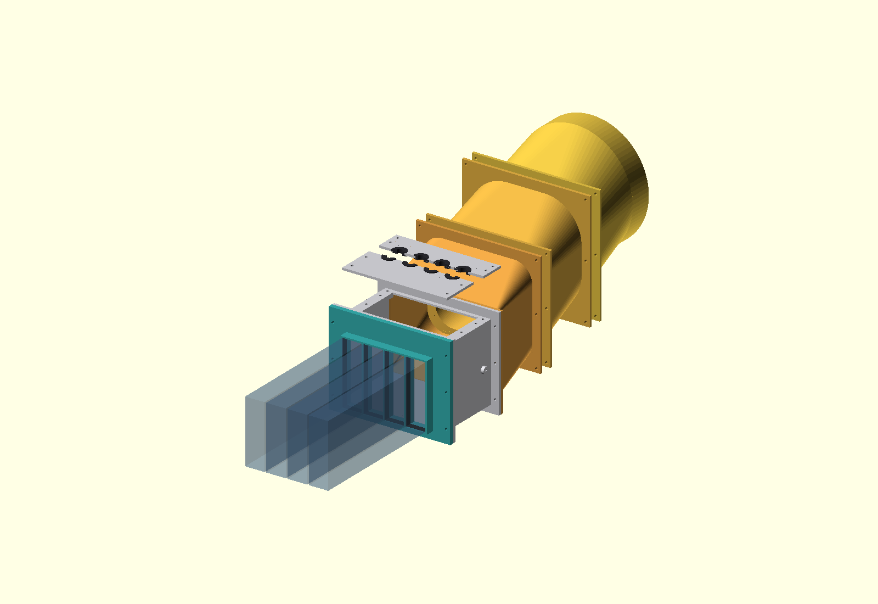
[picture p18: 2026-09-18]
prototype-200w/assembly.png
